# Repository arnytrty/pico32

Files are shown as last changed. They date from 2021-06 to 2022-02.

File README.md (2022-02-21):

# Arnytrty Pico32

Pico32 is small (13mm*13mm) open source board based on ESP32-PICO-D4. It was designed for full use of the SoC package from Espressif & make it more accessible so you can simply handsolder without any special tools. It has a 4MB embedded flash ([esp32-pico-d4 datasheet](https://www.espressif.com/sites/default/files/documentation/esp32-pico-d4_datasheet_en.pdf)).

This board does not have USB to UART converter, you will need an external one to program it (they are pretty cheap). For a programming guide, check out [`FLASHING.md`](FLASHING.md).

---

## Files & Revisions:

Main folders:

| Name | Content |
|:-----|:---|
| hardware | board CAD files |
| images | images of the board |
| models | Exported 3D models |
| order | GERBER, BOM & CPL files |

Subfolders:
| Name | Revision | Tested | Comment |
|:-----|:---:|:---:|:---|
| pico32_v1_jlcpcb_assembly | v1 | YES | got removeable frame to match jlcpcb assembly requirements; designed in [EasyEDA](https://easyeda.com/); fully working, but has pins from bootm & got only 100mA regulator
| pico32_v2 | v2 | NO | pins from side; better regulator; designed in [KiCad](https://www.kicad.org/)
| pico32_v2_jlcpcb_assembly | v2 | NO | got removeable frame to match jlcpcb assembly requirements, other parameters are the same as pico32_v2

***Currently I dont sell these myself, but you can check out how to buy them for yourself on [ORDER.md](ORDER.md) guide.***

# Revisions

## v2

This version is more universal than the first one, it also removes the flaws of v1. It has the same footprint as before (13mm*13mm), but instead of having pads on the bottom, it has them cascellated through holes on sides so you can easily solder it on a homemade PCB.

Known issues:
* NONE

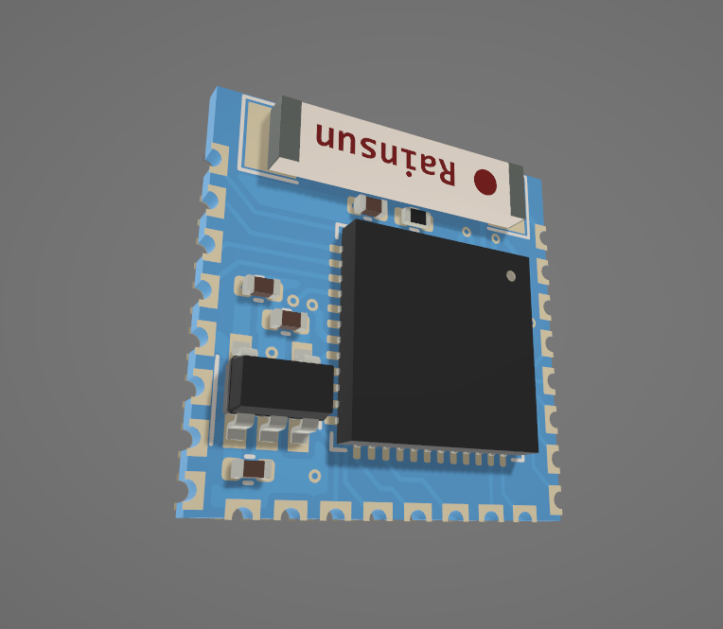
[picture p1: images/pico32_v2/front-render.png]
pico32_v2_front_render

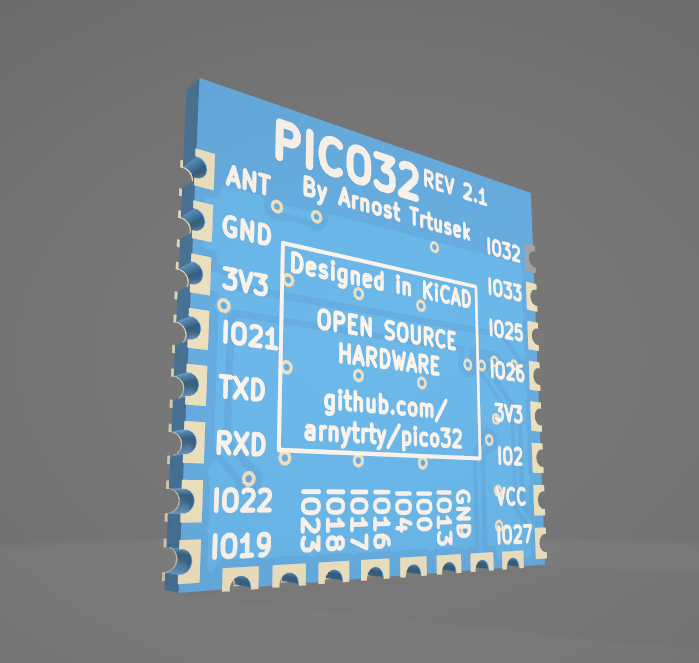
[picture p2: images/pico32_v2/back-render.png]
pico32_v2_back_render


## v1

This was used as the test of how many components ESP32-PICO-D4 needs, it works pretty well, but if you use CPU speed over 80MHz it will throw `Brownout detector was triggered`. With its 13mm*13mm footprint, you can simply fit it in ending of aluminium profile & control rgb leds with it.

Known issues:
* Wrong LDO - only 100mA
* Too small capacitors ?

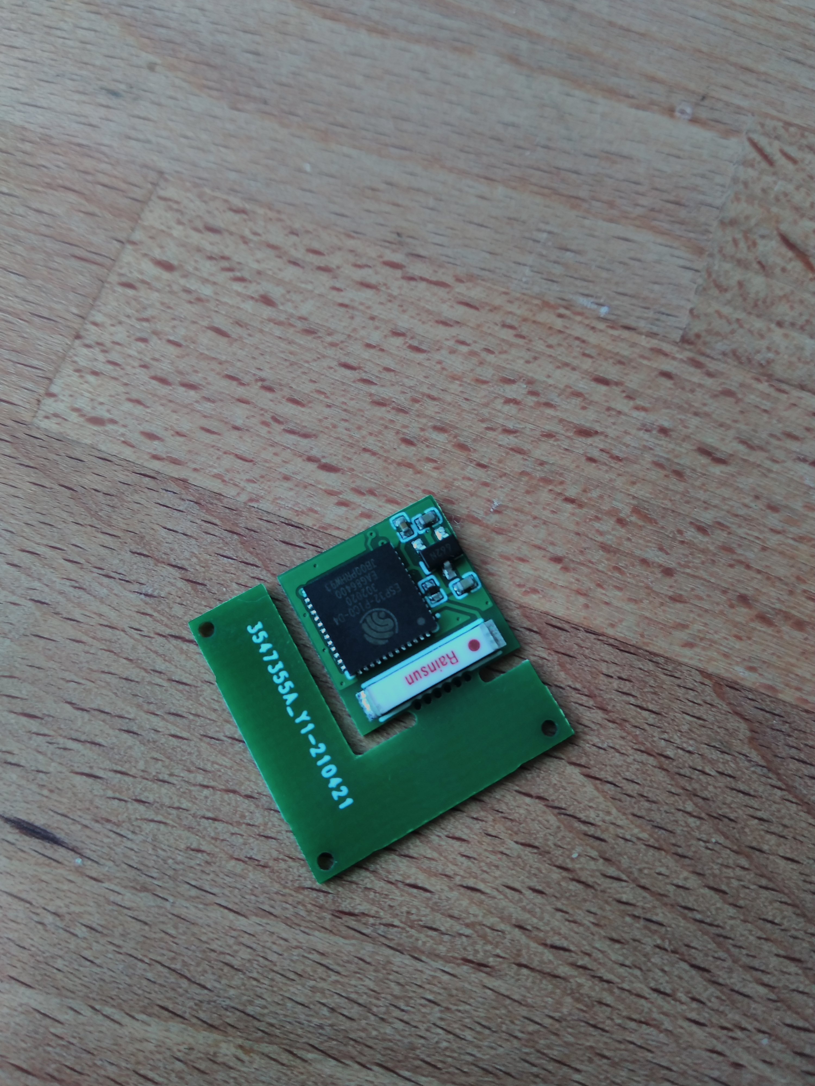
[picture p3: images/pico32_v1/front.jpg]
pico32_v1_front

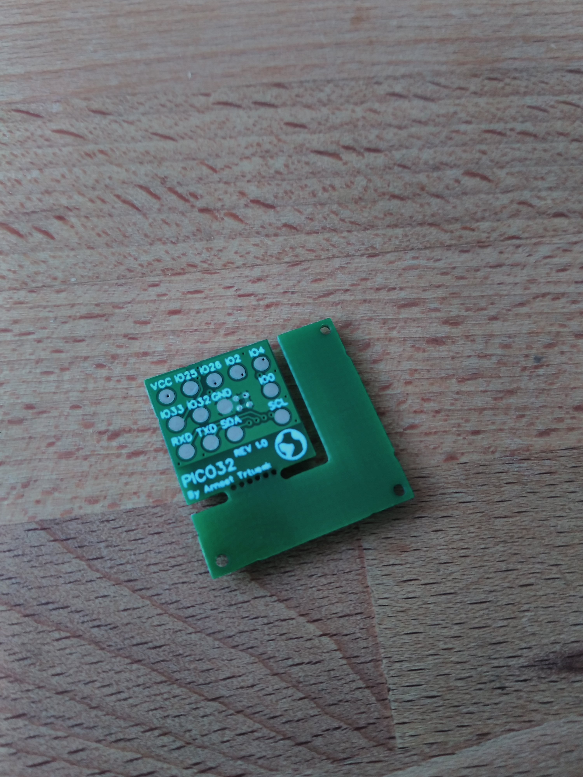
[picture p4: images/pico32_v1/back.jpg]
pico32_v1_back

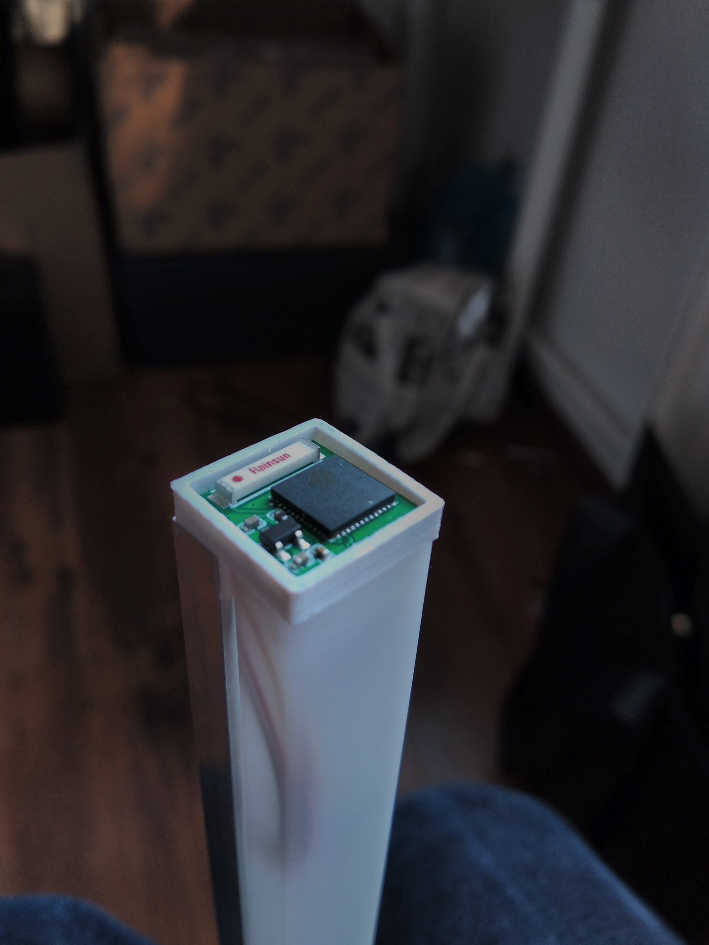
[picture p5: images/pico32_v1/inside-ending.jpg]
pico32_v1_inside_ending

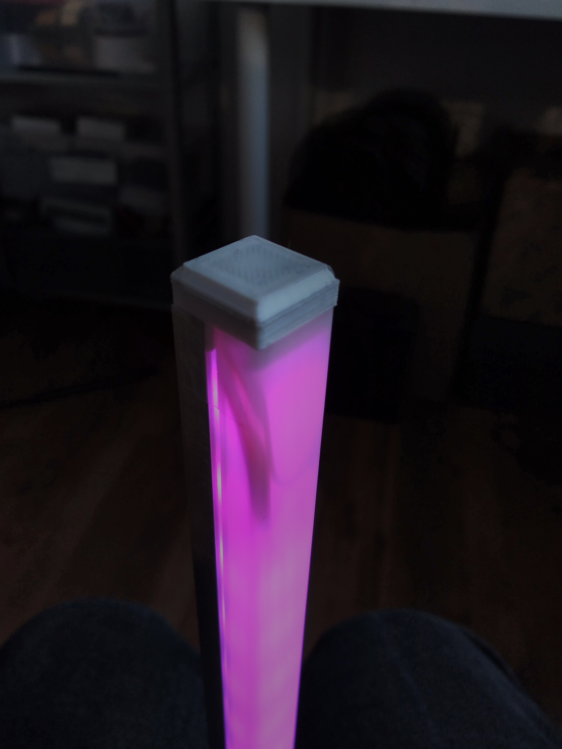
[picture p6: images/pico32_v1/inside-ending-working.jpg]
pico32_v1_inside_ending_working


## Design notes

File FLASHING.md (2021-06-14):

# Flashing Pico32

To program & flash Pico32, you can use supercool extension for [VSCode](https://code.visualstudio.com/) named [PlatformIO](https://platformio.org/). **I will not describe how to install or use PlatformIO, there are plenty tutorials online**.

When you creating new project, for the board select `ESP32 Pico Kit (Espressif)` as the board. You can then use both frameworks. For pins & other information, use [esp32-pico-d4 datasheet](https://www.espressif.com/sites/default/files/documentation/esp32-pico-d4_datasheet_en.pdf).

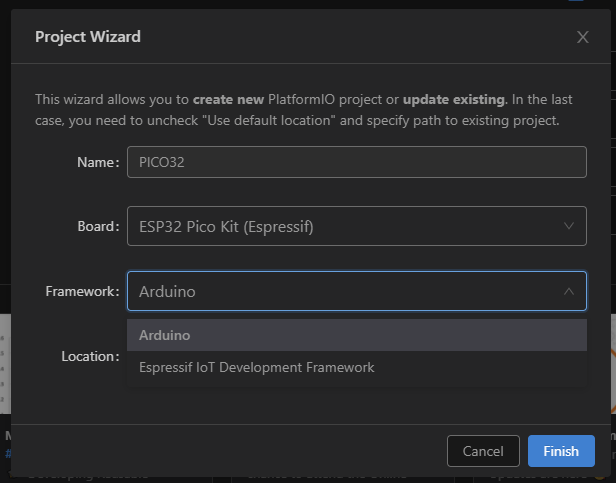
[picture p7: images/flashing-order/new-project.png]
platformio_new_project


If you want to flash the program, connect you USB to UART converter to the board, and **IO0 to GND**, this must be done before you power the board(or reset it) so the esp32-pico-d4 will boot to flashing mode. After finished flashing you have to reset/repower the board without IO0 grounded to start the program. Full explonation of the boot flow & flashing mode is [here](https://github.com/espressif/esptool/wiki/ESP32-Boot-Mode-Selection).

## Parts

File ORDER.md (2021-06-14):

# Ordering Pico32

This is how you can order Pico32 from [JLCPCB](https://jlcpcb.com/).

---

Go to [jlcpcb.com](https://jlcpcb.com/) & click *QUOTE NOW*.

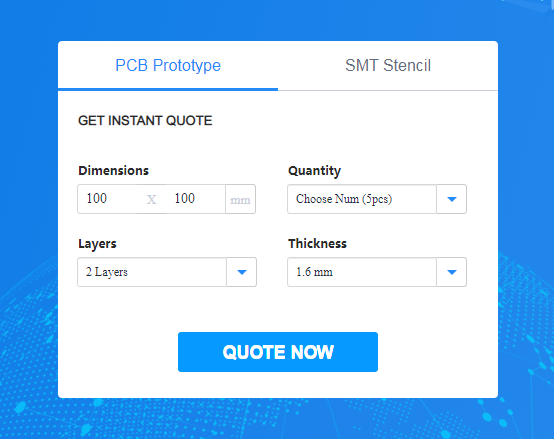
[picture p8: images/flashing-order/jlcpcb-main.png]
jlcpcb_main


Load Gerber (`gerber.zip`) & set PCB thickness to 0.8mm (thinnest for the same price); Remove order number set to Specify Location and if you use revision two - enable Cascellated holes and set to three sides.

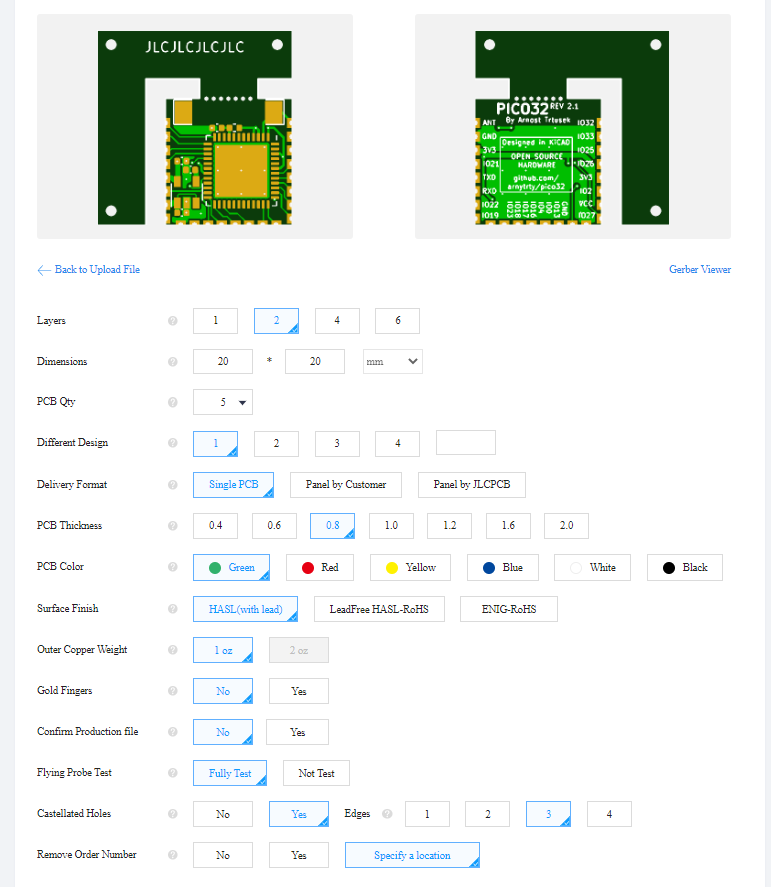
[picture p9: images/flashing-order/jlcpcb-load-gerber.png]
jlcpcb_load_gerber


In bottom enable SMT assembly; set it to top side; set tooling holes to added by customer & Confirm.

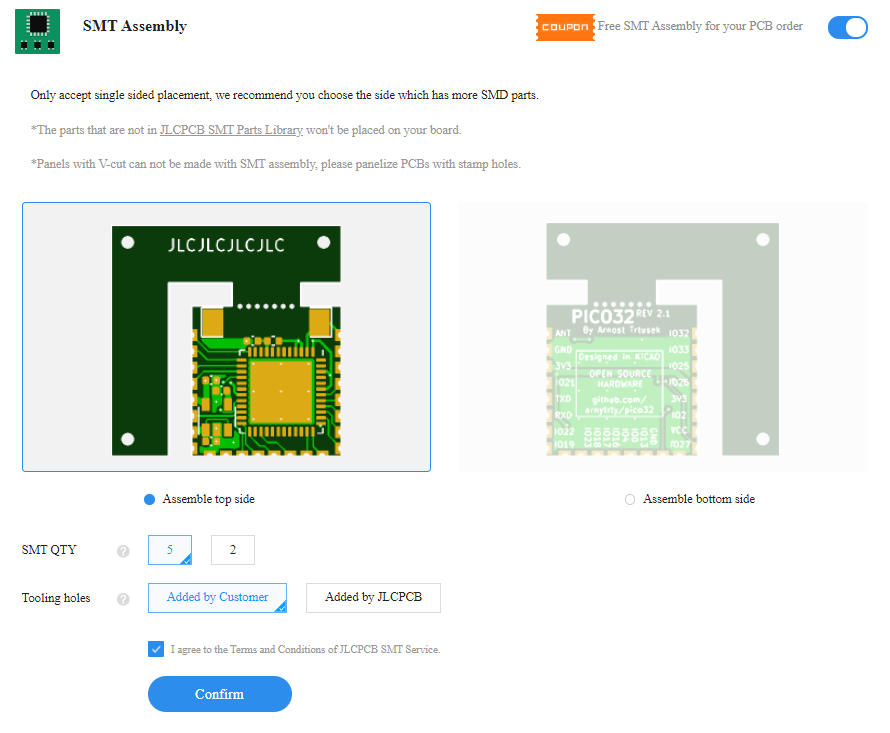
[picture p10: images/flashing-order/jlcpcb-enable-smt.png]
jlcpcb_enable_smt


Add BOM & CPL (`BOM.csv` & `CPL-TOP.csv`) & click next.

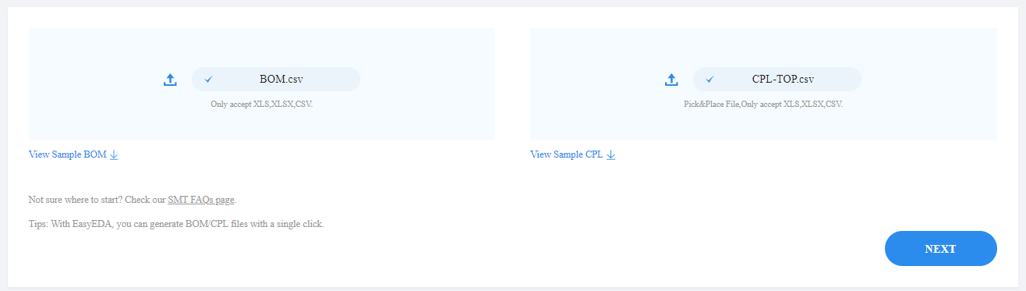
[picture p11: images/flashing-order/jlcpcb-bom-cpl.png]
jlcpcb_bom_cpl


Check if all parts are in stock & click next.

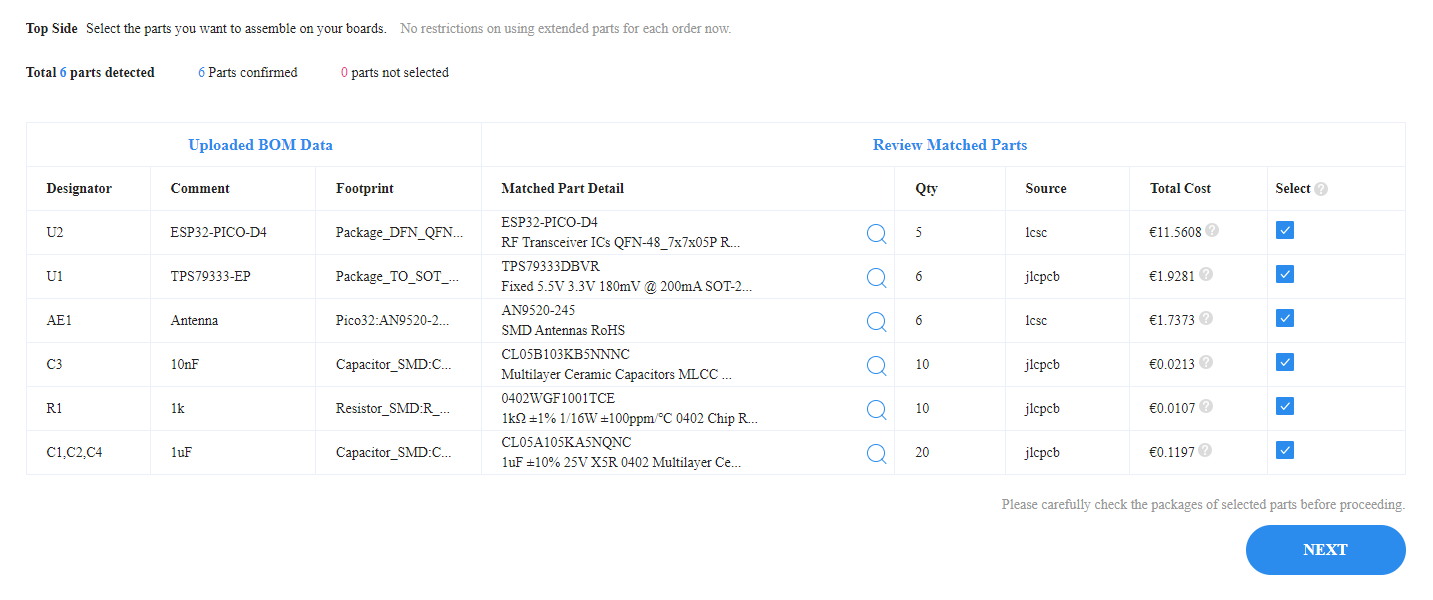
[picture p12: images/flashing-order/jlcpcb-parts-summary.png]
jlcpcb_parts_summary


Check if all parts are well place (they should fix them if not); click save to cart & finish order :D.

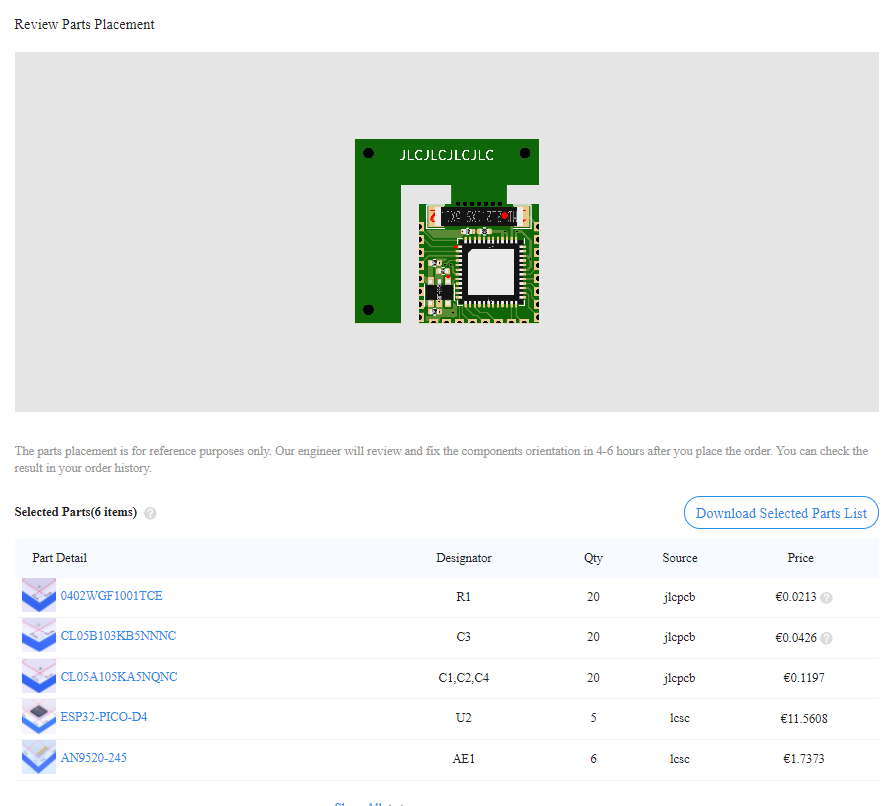
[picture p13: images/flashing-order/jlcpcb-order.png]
jlcpcb_order


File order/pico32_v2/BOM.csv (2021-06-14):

Comment | Designator | Footprint | LCSC
Antenna | AE1 | Pico32:AN9520-245 | C99665
1uF | C1,C2,C4 | Capacitor_SMD:C_0402_1005Metric | C52923
10nF | C3 | Capacitor_SMD:C_0402_1005Metric | C15195
1k | R1 | Resistor_SMD:R_0402_1005Metric | C11702
TPS79333-EP | U1 | Package_TO_SOT_SMD:SOT-23-5 | C9840
ESP32-PICO-D4 | U2 | Package_DFN_QFN:QFN-48-1EP_7x7mm_P0.5mm_EP5.3x5.3mm | C193707

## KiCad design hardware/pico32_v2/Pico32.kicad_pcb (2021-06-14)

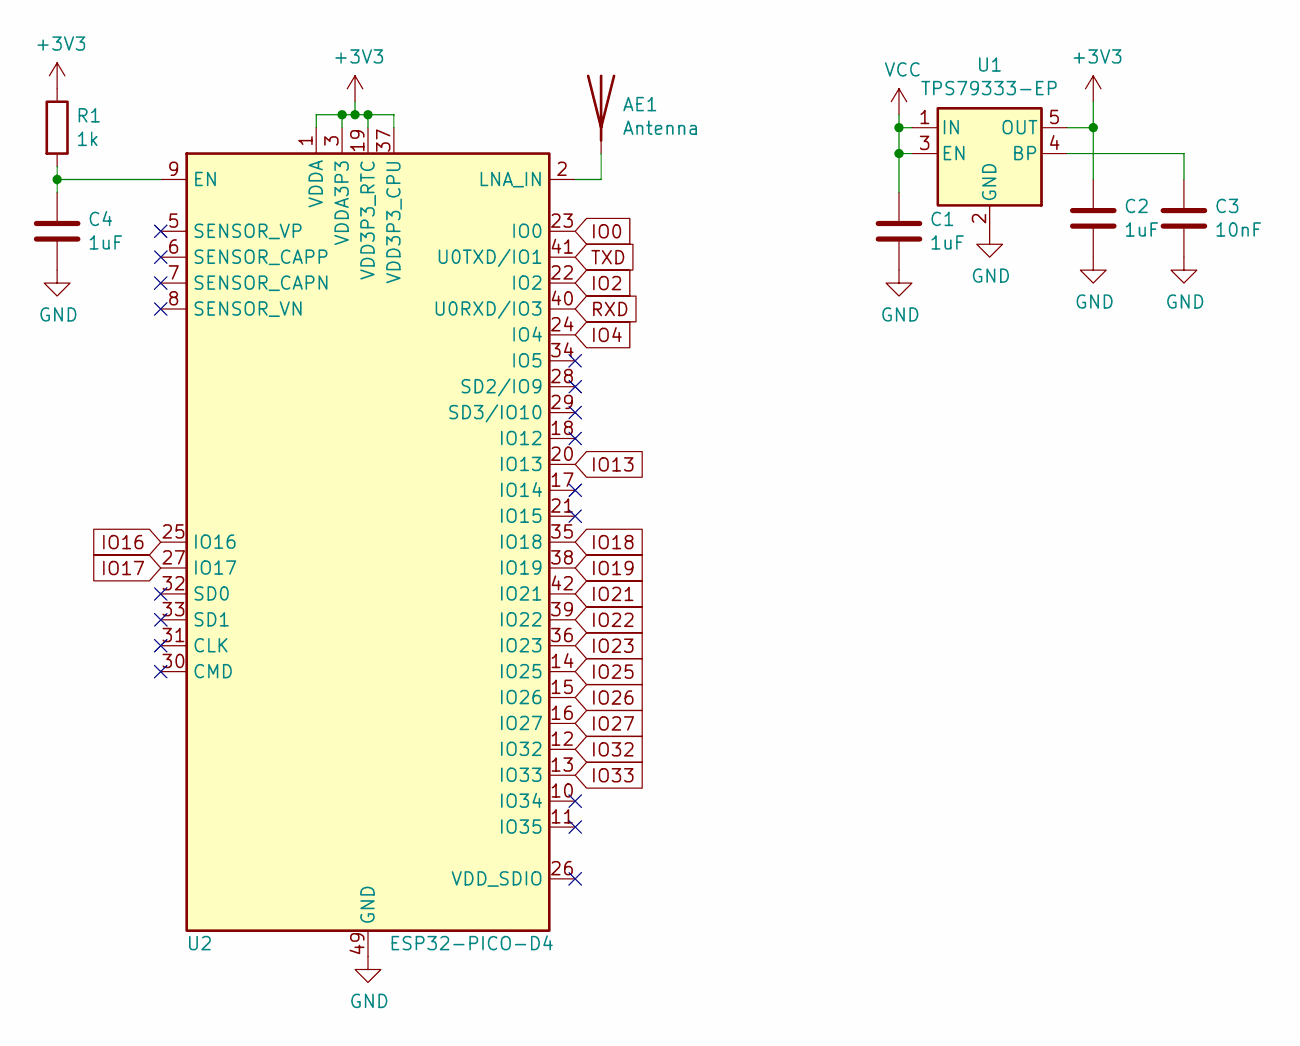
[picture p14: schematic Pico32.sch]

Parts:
AE1: Antenna; AN9520-245; LCSC C99665
C1, C2, C4: 1uF; C_0402_1005Metric; LCSC C52923
C3: 10nF; C_0402_1005Metric; LCSC C15195
R1: 1k; R_0402_1005Metric; LCSC C11702
U1: TPS79333-EP; SOT-23-5; LCSC C9840
U2: ESP32-PICO-D4; QFN-48-1EP_7x7mm_P0.5mm_EP5.3x5.3mm; LCSC C193707

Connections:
+3V3: C2.1, R1.1, U1.5 (OUT), U2.1 (VDDA), U2.3 (VDDA3P3), U2.4 (VDDA3P3), U2.19 (VDD3P3_RTC), U2.37 (VDD3P3_CPU), U2.43 (VDDA), U2.46 (VDDA)
GND: C1.2, C2.2, C3.2, C4.2, U1.2 (GND), U2.49 (GND)
IO0: U2.23 (IO0)
IO2: U2.22 (IO2)
IO4: U2.24 (IO4)
IO13: U2.20 (IO13)
IO16: U2.25 (IO16)
IO17: U2.27 (IO17)
IO18: U2.35 (IO18)
IO19: U2.38 (IO19)
IO21: U2.42 (IO21)
IO22: U2.39 (IO22)
IO23: U2.36 (IO23)
IO25: U2.14 (IO25)
IO26: U2.15 (IO26)
IO27: U2.16 (IO27)
IO32: U2.12 (IO32)
IO33: U2.13 (IO33)
unnamed: AE1.1, U2.2 (LNA_IN)
unnamed: C3.1, U1.4 (BP)
unnamed: C4.1, R1.2, U2.9 (EN)
RXD: U2.40 (U0RXD/IO3)
TXD: U2.41 (U0TXD/IO1)
VCC: C1.1, U1.1 (IN), U1.3 (EN)

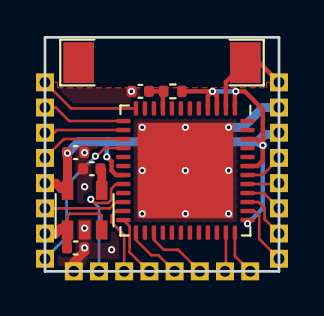
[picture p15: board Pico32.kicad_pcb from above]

Board: 2 copper layers, 13.0 x 13.0 mm, 8 parts (0 on the bottom side), 6 nets.
